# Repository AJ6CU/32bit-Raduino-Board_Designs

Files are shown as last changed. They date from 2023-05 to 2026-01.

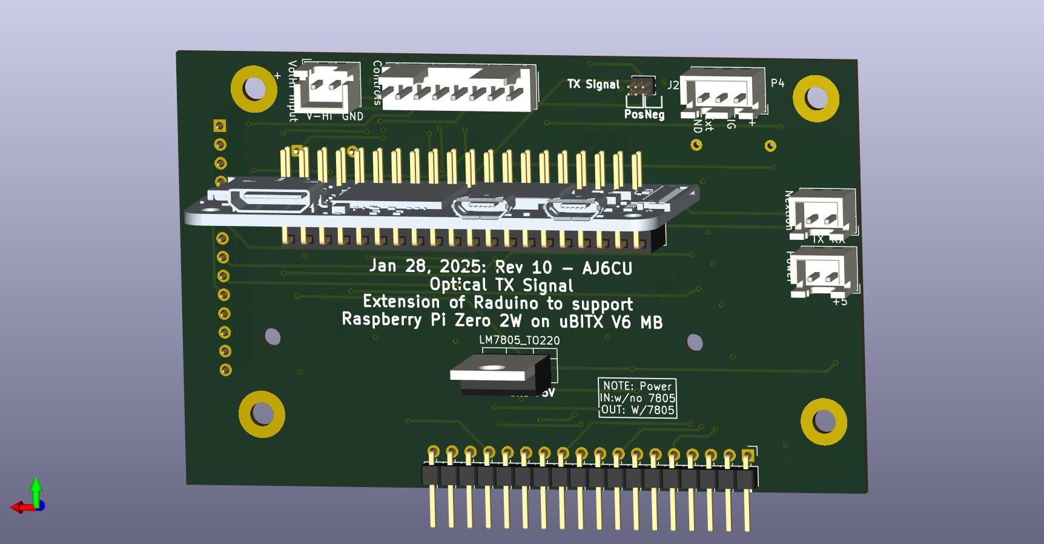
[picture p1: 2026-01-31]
RaduinoClone/RaspberryPiZeroW2/uBitxV6Specific/Images/uBitx V6 Raduino Clone Rev 10-Optic piZero2w-BackView.jpg

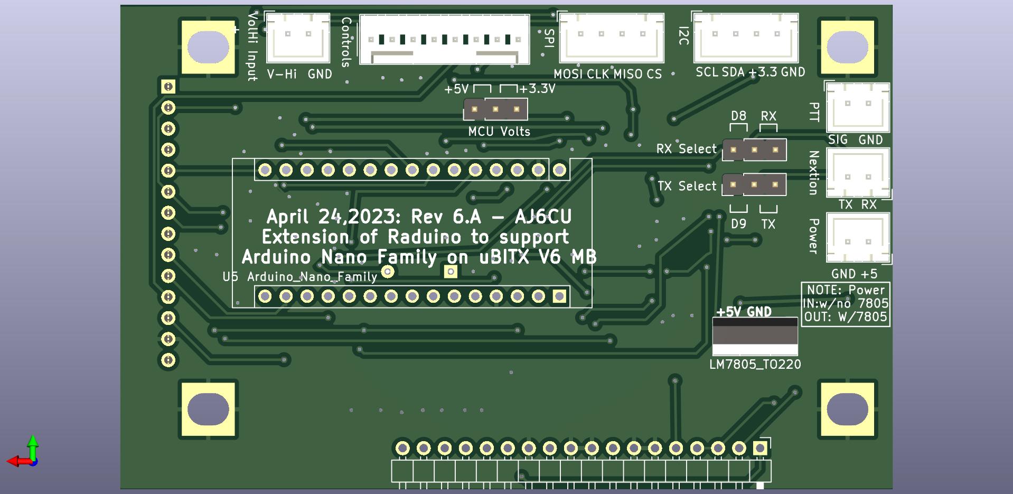
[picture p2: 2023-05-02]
RaduinoClone/Nano Family Nano-Every-IOT-BLE-RP2040/uBitxV6Specific/Images/uBitx V6 Raduino Clone Rev 6.A Arduino Nano Family-rear.jpg

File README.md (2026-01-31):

# An uBitx Raduino for Next Generation Nano, Teensy, RPI PICO and RPI Zero 2W

theheard

The current release of the Raduino board sold by HF Signals only supports the "classic" Arduino nano. This device only has 32kb (actually 30kb with bootloader) of flash, 2kb of sram, and runs at 16mhz. The Classic Nano does have 1kb of EEPROM and is 5V signal compatible which prevents a "drop in replacement" by the new generation of Nano compatible footprint processors. 

The constraint of the "classic" Nano has limited the amount of features that can be implement in firmware. In fact, the popular firmware by Ian Lee (KD8CEC) barely squeezes into the flash memory of the Nano and any new features require tradeoffs of what features are going to be eliminated. It also caused KD8CEC to make some architectural decisions where the UX is implemented on the Nextion screen using some features (i.e. timers) that are difficult to extend and debug. Although I have not looked at the V6 touchscreen software provided by HF Signals, I can reasonably believe that they face a similar contraint as well anybody that wants to hack the software.

The purpose of these boards, are to remove this contraint. Currently the following chips are supported:
  1. Nano
  2. Nano Every
  3. Arduino BLE
  4. Arduino IOT
  5. Arduino RP2040
  6. Teensy 4.0
  7. Raspberry Pi Pico
  8. Raspberry Pi Zero 2W

These boards support both V5 (except for RPI Pico and Zero) and V6. V6 boards require a larger header and the installation of a resister.

73
Mark
AJ6CU

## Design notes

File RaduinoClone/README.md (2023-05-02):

# Raduino Clones
Rev 6.A - May 2, 2023

This directory contains a subdirectory for each processor architecture:

- Nano Family Nano-Every-IOT-BLE-RP2040
- RaspberryPi Pico  
- Teensy 4.0 
- Teensy 4.1

Within each processor directory, there are two subdirectories:

- uBitx V6Specific - this design matches the mechanical and electrial design of the V6 board. The traditional 2x16 LCD header, like in the V6 OEM design, is not on this board. Rather, it includes the TFT LCD design and electrical connections of the V6 TFT LCD.

- uBITX V3456 - this design is compatible with the original Raduino physical characterisics with an LCD header compatible with 2x16. V6 can be supported by using a larger pin header on the bottom and adding the pullup resister. However, this design is likely to have mechanical compatibility problems and so is not recommended for V6 systems using the original V6 case.

And finally each of these directories include:

- BOM - basic bill of materials
- Gerbers - this directory includes a zip file that you should be able to upload to
            your favorite Fab house.
- Images - conceptual 3D models of the board.
- PCBDesign - The designs are done with KiCad V7. You should be able to unzip this backup and directly use it with your tool.
- Schematic - pdf version of the design.

These designs have been sent to the the PCB manufacturer and as of May 2nd, not been tested. There is absolutely no warranty here. Use this at your own risk!

73
Mark Hatch
AJ6CU

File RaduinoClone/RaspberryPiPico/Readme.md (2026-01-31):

Latest version (but untested as of January 31, 2026) is V10. It includes an Optical isolation of TX/RX signal and conversion to a full 3.3V design. Prior version, the Display header was not compatible with the standard V6 2.8 TFT S{I screen. This version should fix this. There is no V10 345 Raduino version.
uBitx V6 Raduino Clone Rev 10-Optic pico-BackView
uBitx V6 Raduino Clone Rev 10-Optic pico-FrontView

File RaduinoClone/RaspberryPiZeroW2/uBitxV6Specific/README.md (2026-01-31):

This is the initial (untested as of January 31, 2026) Raduino V6 using the RPI Zero 2W. There is no software that yet works for this design. My intention is to convert the CEC 2.0 software (see elsewhere in the repositiory) to work with this hardware design.

uBitx V6 Raduino Clone Rev 10-Optic piZero2w-BackView
uBitx V6 Raduino Clone Rev 10-Optic piZero2w-FrontView

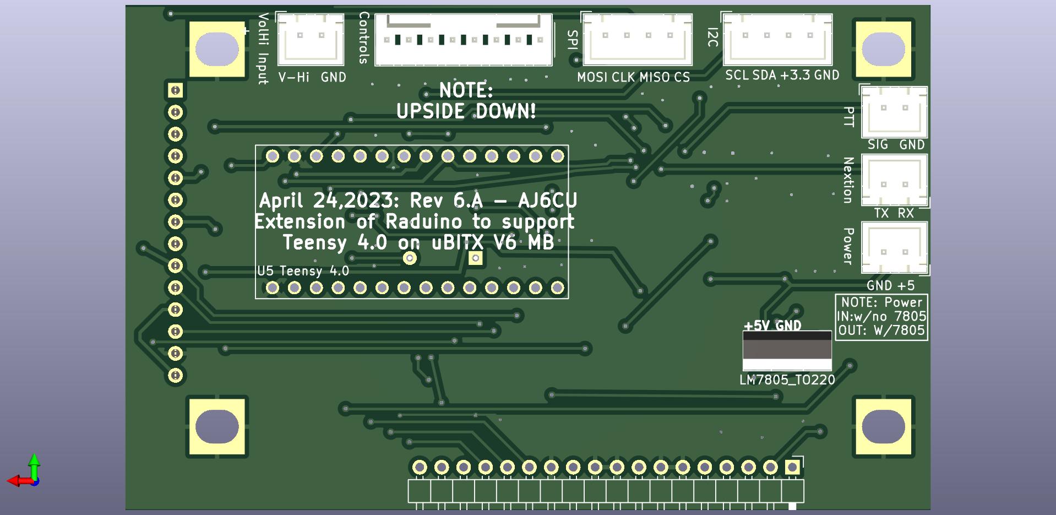
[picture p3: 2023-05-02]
RaduinoClone/Teensy 4.0/uBitxV6Specific/Images/uBitx V6 Raduino Clone Rev 6.A teensy 4.0-rear.jpg

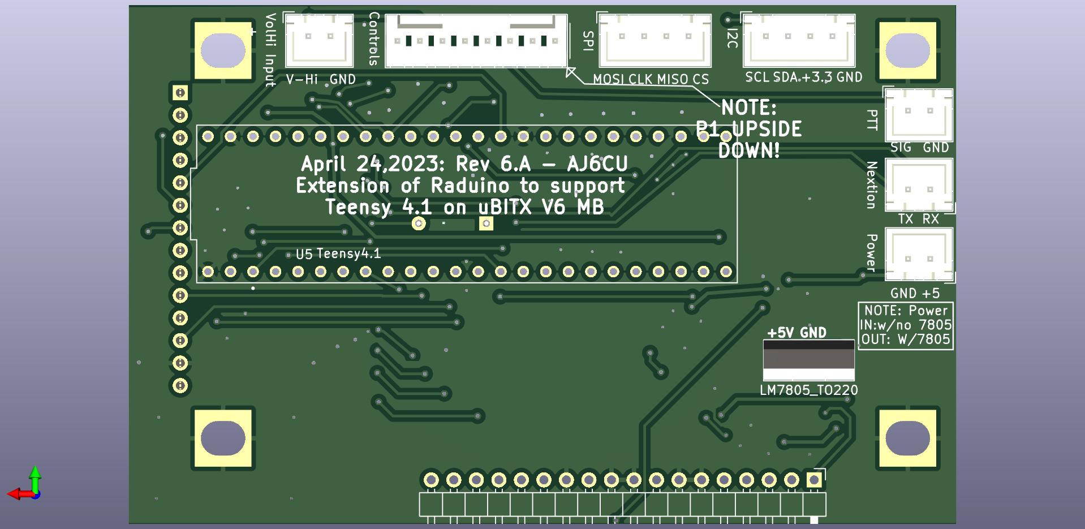
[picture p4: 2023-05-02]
RaduinoClone/Teensy 4.1/uBitxV6Specific/Images/uBitx V6 Raduino Clone Rev 6.A teensy 4.1-rear.jpg

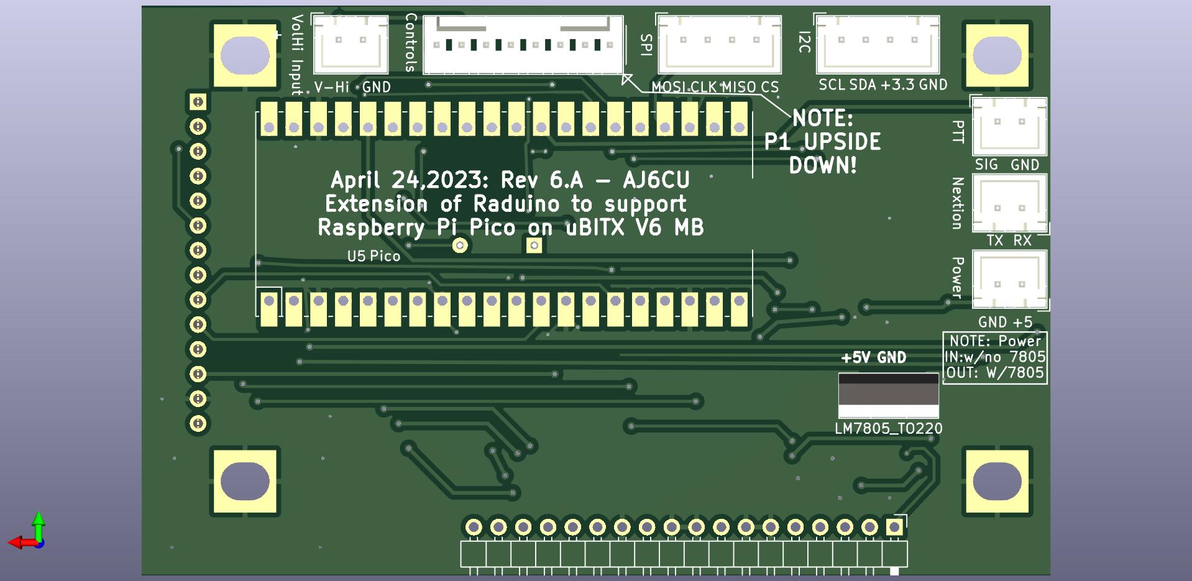
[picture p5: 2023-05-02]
RaduinoClone/RaspberryPiPico/uBitxV6Specific/Images/uBitx V6 Raduino Clone Rev 6.A pico-rear.jpg

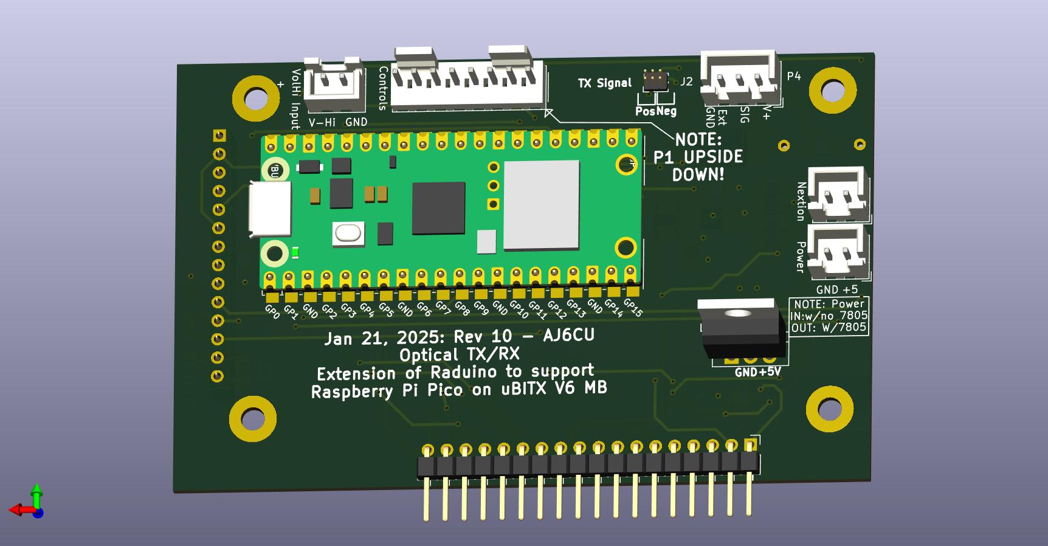
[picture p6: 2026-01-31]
RaduinoClone/RaspberryPiPico/uBitxV6Specific/Images/uBitx V6 Raduino Clone Rev 10-Optic pico-BackView.jpg

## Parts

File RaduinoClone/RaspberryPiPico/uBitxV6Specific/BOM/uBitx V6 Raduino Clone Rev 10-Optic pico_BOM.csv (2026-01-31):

Reference | Qty | Value | DNP | Exclude from BOM | Exclude from Board | Footprint | Datasheet
C1,C2,C4,C5,C6,C8,C11 | 7 | 0.1u |  |  |  | Capacitor_SMD:C_1206_3216Metric | ~
C3 | 1 | 0.3nF |  |  |  | Capacitor_SMD:C_1206_3216Metric | ~
C7 | 1 | 0.33u |  |  |  | Capacitor_SMD:C_1206_3216Metric | ~
C9 | 1 | 1uf |  |  |  | Capacitor_SMD:C_1206_3216Metric | ~
C10 | 1 | 10uf |  |  |  | Capacitor_SMD:C_1206_3216Metric | ~
D1 | 1 | 1N4148 |  |  |  | MyLibrary:tht_SMD_Diode | https://assets.nexperia.com/documents/data-sheet/1N4148_1N4448.pdf
J1 | 1 | LCD DISPLAY |  |  |  | Connector_PinSocket_2.54mm:PinSocket_1x14_P2.54mm_Vertical | ~
J2 | 1 | TX Polarity Sel |  |  |  | Connector_PinHeader_1.00mm:PinHeader_2x03_P1.00mm_Vertical | ~
P1 | 1 | Controls |  |  |  | MyLibrary:Molex_KK-254_AE-6410-08A_1x08_P2.54mm_Vertical-reversed | ~
P2 | 1 | Power |  |  |  | Connector_JST:JST_XH_B2B-XH-A_1x02_P2.50mm_Vertical | ~
P3 | 1 | Oscillators |  |  |  | MyLibrary:PinHeadere_1x18_P2.54mm_Horizontal | ~
P4 | 1 | TX/RX |  |  |  | Connector_JST:JST_XH_B3B-XH-AM_1x03_P2.50mm_Vertical | ~
P5 | 1 | Nextion |  |  |  | Connector_JST:JST_XH_B2B-XH-A_1x02_P2.50mm_Vertical | ~
P7 | 1 | VolHi Input |  |  |  | Connector_JST:JST_XH_B2B-XH-A_1x02_P2.50mm_Vertical | ~
R1 | 1 | 10k |  |  |  | Resistor_SMD:R_1206_3216Metric | ~
R2 | 1 | 1K |  |  |  | Resistor_SMD:R_1206_3216Metric | ~
R3 | 1 | 4.7k |  |  |  | Resistor_SMD:R_1206_3216Metric | ~
R4 | 1 | 22 |  |  |  | Resistor_SMD:R_1206_3216Metric | ~
R5 | 1 | 1k |  |  |  | Resistor_SMD:R_1206_3216Metric | ~
R6 | 1 | 10k |  |  |  | MyLibrary:resistor-tht-1206smd-combo | ~
R13,R14 | 2 | 2.2k |  |  |  | Resistor_SMD:R_1206_3216Metric | ~
U1 | 1 | LM7805_TO220 |  |  |  | Package_TO_SOT_THT:TO-220-3_Vertical | https://www.onsemi.cn/PowerSolutions/document/MC7800-D.PDF
U2 | 1 | Si5351A-B-GT |  |  |  | Package_SO:MSOP-10_3x3mm_P0.5mm | https://www.silabs.com/documents/public/data-sheets/Si5351-B.pdf
U3 | 1 | LM358DR |  |  |  | Package_SO:SOIC-8_3.9x4.9mm_P1.27mm | http://www.ti.com/lit/ds/symlink/lm2904-n.pdf
U4 | 1 | CAT24C256 |  |  |  | Package_SO:SOIC-8_3.9x4.9mm_P1.27mm | https://www.onsemi.cn/PowerSolutions/document/CAT24C256-D.PDF
U5 | 1 | Pico |  |  |  | MyLibrary:RPi_Pico_TH_SMD_defined
U6 | 1 | LTV-817S |  |  |  | Package_DIP:SMDIP-4_W9.53mm | http://www.us.liteon.com/downloads/LTV-817-827-847.PDF
Y1 | 1 | 25M |  |  |  | Crystal:Crystal_SMD_5032-2Pin_5.0x3.2mm | ~

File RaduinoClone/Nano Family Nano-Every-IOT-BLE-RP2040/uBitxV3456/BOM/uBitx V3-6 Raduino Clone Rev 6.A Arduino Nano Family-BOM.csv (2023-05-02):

Item | Qty | Reference(s) | Value | Footprint | Digikey | Comment
1 | 5 | C1, C2, C4, C5, C6 | 0.1u | Capacitor_SMD:C_1206_3216Metric |  | Purchase a "kit" from Amazon, eBay, AliExpress
2 | 1 | C3 | 0.3nF | Capacitor_SMD:C_1206_3216Metric |  | https://www.amazon.com/gp/product/B06XDHC93D/
3 | 1 | C7 | 0.1uF | Capacitor_SMD:C_1206_3216Metric
4 | 1 | C8 | 0.33uF | Capacitor_SMD:C_1206_3216Metric
5 | 1 | D1 | 1N4148TR | Diode_THT:D_DO-35_SOD27_P7.62mm_Horizontal | 1N4148TR
6 | 1 | JP1 | MCU Volts | Connector_PinHeader_2.54mm:PinHeader_1x03_P2.54mm_Vertical |  | Purchase a "kit" from Amazon, eBay, AliExpress
7 | 1 | JP2 | RX Select | Connector_PinHeader_2.54mm:PinHeader_1x03_P2.54mm_Vertical
8 | 1 | JP3 | TX Select | Connector_PinHeader_2.54mm:PinHeader_1x03_P2.54mm_Vertical
9 | 1 | P1 | Controls | Molex_KK-254_AE-6410-08A_1x08_P2.54mm_Vertical |  | https://www.amazon.com/gp/product/B09P3W4VBQ
10 | 1 | P2 | LCD Display | Connector_PinSocket_2.54mm:PinSocket_1x16_P2.54mm_Vertical |  | Purchase a "kit" from Amazon, eBay, AliExpress
11 | 1 | P3 | SPI | Connector_JST:JST_XH_B4B-XH-A_1x04_P2.50mm_Vertical |  | Purchase a "kit" from Amazon, eBay, AliExpress
12 | 1 | P5 | Nextion | Connector_JST:JST_XH_B2B-XH-A_1x02_P2.50mm_Vertical |  | Vertical | https://www.amazon.com/gp/product/B0791DJMW10
13 | 1 | P6 | I2C | Connector_JST:JST_XH_B4B-XH-A_1x04_P2.50mm_Vertical |  | Horizontal | https://www.ebay.com/itm/292219710596
14 | 1 | P7 | VolHi Input | Connector_JST:JST_XH_B2B-XH-A_1x02_P2.50mm_Vertical
15 | 1 | P8 | Oscillators | PinHeader_1x18_P2.54mm_Horizontal
16 | 1 | P9 | PTT | Connector_JST:JST_XH_B2B-XH-A_1x02_P2.50mm_Vertical
17 | 1 | R1 | 10k | Resistor_SMD:R_1206_3216Metric |  | Purchase a "kit" from Amazon, eBay, AliExpress
18 | 1 | R2 | 1K | Resistor_SMD:R_1206_3216Metric |  | https://www.amazon.com/gp/product/B07G4YJCNC
19 | 1 | R3 | 4.7k | Resistor_SMD:R_1206_3216Metric
20 | 2 | R13, R14 | 2.2k | Resistor_SMD:R_1206_3216Metric
21 | 1 | RV1 | 10k | Potentiometer_THT:Potentiometer_Vishay_T73YP_Vertical |  | https://www.amazon.com/gp/product/B082ZVSR8K/
22 | 1 | U1 | Arduino_Nano_v3.x | Arduino_Nano Family (Nano,Every,IOT,BLE, RP2040) upside-down soldered - usb on bottom
23 | 1 | U2 | Si5351A-B-GT | Package_SO:MSOP-10_3x3mm_P0.5mm | 336-2399-5-ND
24 | 1 | U3 | LM358DR | Package_SO:SOIC-8_3.9x4.9mm_P1.27mm | LM358DR2G
25 | 1 | U4 | CAT24C256 | Package_SO:SOIC-8_3.9x4.9mm_P1.27mm | CAT24C256WI-GT3
26 | 1 | U5 | LM7805_TO220 | Package_TO_SOT_THT:TO-220-3_Vertical |  | https://www.amazon.com/gp/product/B01MSE2R8C
27 | 1 | Y1 | 25M | Crystal:Crystal_SMD_5032-2Pin_5.0x3.2mm | 644-1041-2-ND

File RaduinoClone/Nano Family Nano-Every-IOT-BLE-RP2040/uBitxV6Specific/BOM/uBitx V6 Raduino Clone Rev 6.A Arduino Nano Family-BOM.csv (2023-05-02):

Item | Qty | Reference(s) | Value | Description | Digikey | Comment
1 | 6 | C1, C2, C4, C5, C6, C11 | 0.1u | Capacitor_SMD:C_1206_3216Metric |  | Purchase a "kit" from Amazon, eBay, AliExpress
2 | 1 | C3 | 0.3nF | Capacitor_SMD:C_1206_3216Metric |  | https://www.amazon.com/gp/product/B06XDHC93D/
3 | 1 | C7 | 0.33uF | Capacitor_SMD:C_1206_3216Metric
4 | 1 | C8 | 0.1uF | Capacitor_SMD:C_1206_3216Metric
5 | 1 | C9 | 1uf | Capacitor_SMD:C_1206_3216Metric
6 | 1 | C10 | 10uf | Capacitor_SMD:C_1206_3216Metric
7 | 1 | D1 | 1N4148TR | Diode_THT:D_DO-35_SOD27_P7.62mm_Horizontal | 1N4148TR
8 | 1 | J1 | LCD DISPLAY | Connector_PinSocket_2.54mm:PinSocket_1x14_P2.54mm_Vertical |  | Purchase a "kit" from Amazon, eBay, AliExpress
9 | 1 | JP1 | MCU Volts | Connector_PinHeader_2.54mm:PinHeader_1x03_P2.54mm_Vertical |  | Purchase a "kit" from Amazon, eBay, AliExpress
10 | 1 | JP2 | RX Select | Connector_PinHeader_2.54mm:PinHeader_1x03_P2.54mm_Vertical
11 | 1 | JP3 | TX Select | Connector_PinHeader_2.54mm:PinHeader_1x03_P2.54mm_Vertical
12 | 1 | P1 | Controls | Molex_KK-254_AE-6410-08A_1x08_P2.54mm_Vertical-reversed |  | https://www.amazon.com/gp/product/B09P3W4VBQ
13 | 1 | P2 | Power | Connector_JST:JST_XH_B2B-XH-A_1x02_P2.50mm_Vertical
14 | 1 | P3 | Oscillators | PinHeader_x18_P2.54mm_Horizontal
15 | 1 | P5 | Nextion | Connector_JST:JST_XH_B2B-XH-A_1x02_P2.50mm_Vertical |  | Purchase a "kit" from Amazon, eBay, AliExpress
16 | 1 | P6 | I2C | Connector_JST:JST_XH_B4B-XH-A_1x04_P2.50mm_Vertical |  | Vertical | https://www.amazon.com/gp/product/B0791DJMW10
17 | 1 | P7 | VolHi Input | Connector_JST:JST_XH_B2B-XH-A_1x02_P2.50mm_Vertical |  | Horizontal | https://www.ebay.com/itm/292219710596
18 | 1 | P8 | SPI | Connector_JST:JST_XH_B4B-XH-A_1x04_P2.50mm_Vertical
19 | 1 | P9 | PTT | Connector_JST:JST_XH_B2B-XH-A_1x02_P2.50mm_Vertical
20 | 1 | R1 | 10k | Resistor_SMD:R_1206_3216Metric |  | Purchase a "kit" from Amazon, eBay, AliExpress
21 | 1 | R2 | 1K | Resistor_SMD:R_1206_3216Metric |  | https://www.amazon.com/gp/product/B07G4YJCNC
22 | 1 | R3 | 4.7k | Resistor_SMD:R_1206_3216Metric
23 | 1 | R4 | 22R | Resistor_SMD:R_1206_3216Metric
24 | 2 | R13, R14 | 2.2k | Resistor_SMD:R_1206_3216Metric
25 | 1 | U1 | LM7805_TO220 | Package_TO_SOT_THT:TO-220-3_Vertical |  | https://www.amazon.com/gp/product/B01MSE2R8C
26 | 1 | U2 | Si5351A-B-GT | Package_SO:MSOP-10_3x3mm_P0.5mm | 336-2399-5-ND
27 | 1 | U3 | LM358DR | Package_SO:SOIC-8_3.9x4.9mm_P1.27mm | LM358DR2G
28 | 1 | U4 | CAT24C256 | Package_SO:SOIC-8_3.9x4.9mm_P1.27mm | CAT24C256WI-GT3
29 | 1 | U5 | Arduino_Nano_Family | Nano: Nano V3.0, Every, IOT, BLE, RP2040
30 | 1 | Y1 | 25M | Crystal:Crystal_SMD_5032-2Pin_5.0x3.2mm | 644-1041-2-ND

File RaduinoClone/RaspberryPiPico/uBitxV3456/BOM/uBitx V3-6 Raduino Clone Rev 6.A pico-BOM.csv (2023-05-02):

Item | Qty | Reference(s) | Value | Description | Digikey | Comment
1 | 5 | C1, C2, C4, C5, C6 | 0.1u | Capacitor_SMD:C_1206_3216Metric |  | Purchase a "kit" from Amazon, eBay, AliExpress
2 | 1 | C3 | 0.3nF | Capacitor_SMD:C_1206_3216Metric |  | https://www.amazon.com/gp/product/B06XDHC93D/
3 | 1 | C7 | 0.1uF | Capacitor_SMD:C_1206_3216Metric
4 | 1 | C8 | 0.33uF | Capacitor_SMD:C_1206_3216Metric
5 | 1 | D1 | 1N4148TR | Diode_THT:D_DO-35_SOD27_P7.62mm_Horizontal | 1N4148TR
6 | 1 | P1 | Controls | Molex_KK-254_AE-6410-08A_1x08_P2.54mm_Vertical |  | https://www.amazon.com/gp/product/B09P3W4VBQ
7 | 1 | P2 | LCD Display | Connector_PinSocket_2.54mm:PinSocket_1x16_P2.54mm_Vertical |  | Purchase a "kit" from Amazon, eBay, AliExpress
8 | 1 | P3 | Oscillators | PinHeader_1x18_P2.54mm_Horizontal |  | Purchase a "kit" from Amazon, eBay, AliExpress
9 | 1 | P5 | Nextion | Connector_JST:JST_XH_B2B-XH-A_1x02_P2.50mm_Vertical |  | Purchase a "kit" from Amazon, eBay, AliExpress
10 | 1 | P6 | I2C | Connector_JST:JST_XH_B4B-XH-A_1x04_P2.50mm_Vertical |  | Vertical | https://www.amazon.com/gp/product/B0791DJMW10
11 | 1 | P7 | VolHi Input | Connector_JST:JST_XH_B2B-XH-A_1x02_P2.50mm_Vertical |  | Horizontal | https://www.ebay.com/itm/292219710596
12 | 1 | P8 | SPI | Connector_JST:JST_XH_B4B-XH-A_1x04_P2.50mm_Vertical
13 | 1 | P9 | PTT | Connector_JST:JST_XH_B2B-XH-A_1x02_P2.50mm_Vertical
14 | 1 | R1 | 10k | Resistor_SMD:R_1206_3216Metric |  | Purchase a "kit" from Amazon, eBay, AliExpress
15 | 1 | R2 | 1K | Resistor_SMD:R_1206_3216Metric |  | https://www.amazon.com/gp/product/B07G4YJCNC
16 | 1 | R3 | 4.7k | Resistor_SMD:R_1206_3216Metric
17 | 2 | R13, R14 | 2.2k | Resistor_SMD:R_1206_3216Metric
18 | 1 | RV1 | 10k | Potentiometer_THT:Potentiometer_Vishay_T73YP_Vertical |  | https://www.amazon.com/gp/product/B082ZVSR8K/
19 | 1 | U1 | LM7805_TO220 | Package_TO_SOT_THT:TO-220-3_Vertical |  | https://www.amazon.com/gp/product/B01MSE2R8C
20 | 1 | U2 | Si5351A-B-GT | Package_SO:MSOP-10_3x3mm_P0.5mm | 336-2399-5-ND
21 | 1 | U3 | LM358DR | Package_SO:SOIC-8_3.9x4.9mm_P1.27mm | LM358DR2G
22 | 1 | U4 | CAT24C256 | Package_SO:SOIC-8_3.9x4.9mm_P1.27mm | CAT24C256WI-GT3
23 | 1 | U5 | Pico | Raspberry Pi Pico/Pico-W
24 | 1 | Y1 | 25M | Crystal:Crystal_SMD_5032-2Pin_5.0x3.2mm | 644-1041-2-ND

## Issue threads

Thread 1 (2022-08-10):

RX/TX and D8/D9 do not agree.

AJ6CU, 2022-08-10:
Revise wiring to ensure the RX pins (RX0 and D8, TX0 and D9). Have to flip the connector when switching between RX/TX and D8/D9.

AJ6CU, 2022-10-26:
fixed in v3

Closed 2022-10-26.

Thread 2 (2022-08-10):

s-meter chip footprint too small for human soldering

AJ6CU, 2022-08-10:
The 358 chip surface mount footprint is very small. Probably beyond most people's capability. Need to select a larger footprint.

AJ6CU, 2022-08-15:
wrong footprint on board. real footprint is human solderable.

AJ6CU, 2022-10-26:
fixed in v3

Closed 2022-08-15.

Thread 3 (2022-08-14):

wrong footprint for LM358DR

AJ6CU, 2022-08-14:

AJ6CU, 2022-10-26:
fixed in v3

Closed 2022-10-26.

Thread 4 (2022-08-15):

Voltage Hi input too far away from volume put.

AJ6CU, 2022-08-15:
Connector needs to be moved to right side to minimize length of cable.

AJ6CU, 2022-10-26:
fixed in v3

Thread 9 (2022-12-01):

boards sit too low for V6 and use of LCD

AJ6CU, 2022-12-01:
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

AJ6CU, 2023-04-25:
creating seperate v6 raduino. V3,4,5  all in one not expected to fit. v6

Closed 2023-04-25.

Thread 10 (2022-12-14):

LCD en/rs pins not the same on all boards

AJ6CU, 2022-12-14:
Probably should always be D8 and D( as in original.

AJ6CU, 2023-03-21:
Also Rapsberrypi Pico needs to be changed.

AJ6CU, 2023-04-24:
Fixed on Pico. Breaks accessibility of RX/TX for nextion from the LCD header.

AJ6CU, 2023-04-25:
fixed in v5 on teensy and pico

Closed 2023-04-25.

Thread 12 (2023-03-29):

move the fbutton on pico to gpio28_ADC2 to allow use of extended button feature of KD8CEC

AJ6CU, 2023-03-29:

AJ6CU, 2023-04-24:
fixed in v5

Closed 2023-04-24.

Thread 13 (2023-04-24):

teensy add support for pins on underside of the board

AJ6CU, 2023-04-24:
This is in  prep for use of airlift for web access.

AJ6CU, 2023-04-27:
decided to defer this. Teensy 4.0 SPI pins continue to conflict with LED.

Closed 2023-04-27.

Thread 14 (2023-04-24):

add header for spi bus to  support air lift.

AJ6CU, 2023-04-24:
this function on nanos will be a tradeoff between lcd and extended filter support. can't have everything.

AJ6CU, 2023-04-26:
done on teensy and pico. Needs to be done on Arduino board.

AJ6CU, 2023-04-27:
done

Closed 2023-04-27.

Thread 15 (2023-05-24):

on pico v6 (and probably 3-5, swap encoder B and encoder A pins to be consistent with rest of world.

AJ6CU, 2023-05-24:

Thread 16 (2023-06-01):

spi header should be order of data lines

AJ6CU, 2023-06-01:
Currently, the SPI header is:
Pin     GPIO   Function
1        D11     Mosi
2        D13     SCK
3        D12     MISO
4        D10     SS

The header should be in order of the GPIO pins
1        D10     SS
2        D11     MOSI
3        D12     MISO
4        D13     SCK

This would allow easier use of this header for the extended filters functionality. The 4 pins could be used to identify band and help drive selection of antenna (for example).

No harm the way they are, just weird and no reason they are in that order...

Might want to check other offboard connectors to see if they are similarly messed up.

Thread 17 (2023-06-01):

PTT header not what it was supposed to be...

AJ6CU, 2023-06-01:
The original idea for the PTT header was to drive a RF switch between the radio and an attached SDR. However, the PTT line is an input of the microphone and *not* turned on during CW or other modes.   The T/R pin (D7) was what I was looking for.

Logic is reversed, T is positive and R is negative. Would require an inverter to use for an rf switch.

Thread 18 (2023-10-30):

Pico (and perhaps other) LCD display that supports SPI displays using wrong pins

AJ6CU, 2023-10-30:
Designs up thru V7 of Pico are not using the right pins on the LCD/TFT header. Specifically:

PIN      v7     v8(in draft)
SCK     13     10
CS       10     13
D_C     9       8
Touch  8       9

Pin selection probably was related to mthe original LCD 2x16 header and the pins have changed for SPI bus#1 on the PICO

This is fixed on the schematic for V8 but not yet propagated to board level.

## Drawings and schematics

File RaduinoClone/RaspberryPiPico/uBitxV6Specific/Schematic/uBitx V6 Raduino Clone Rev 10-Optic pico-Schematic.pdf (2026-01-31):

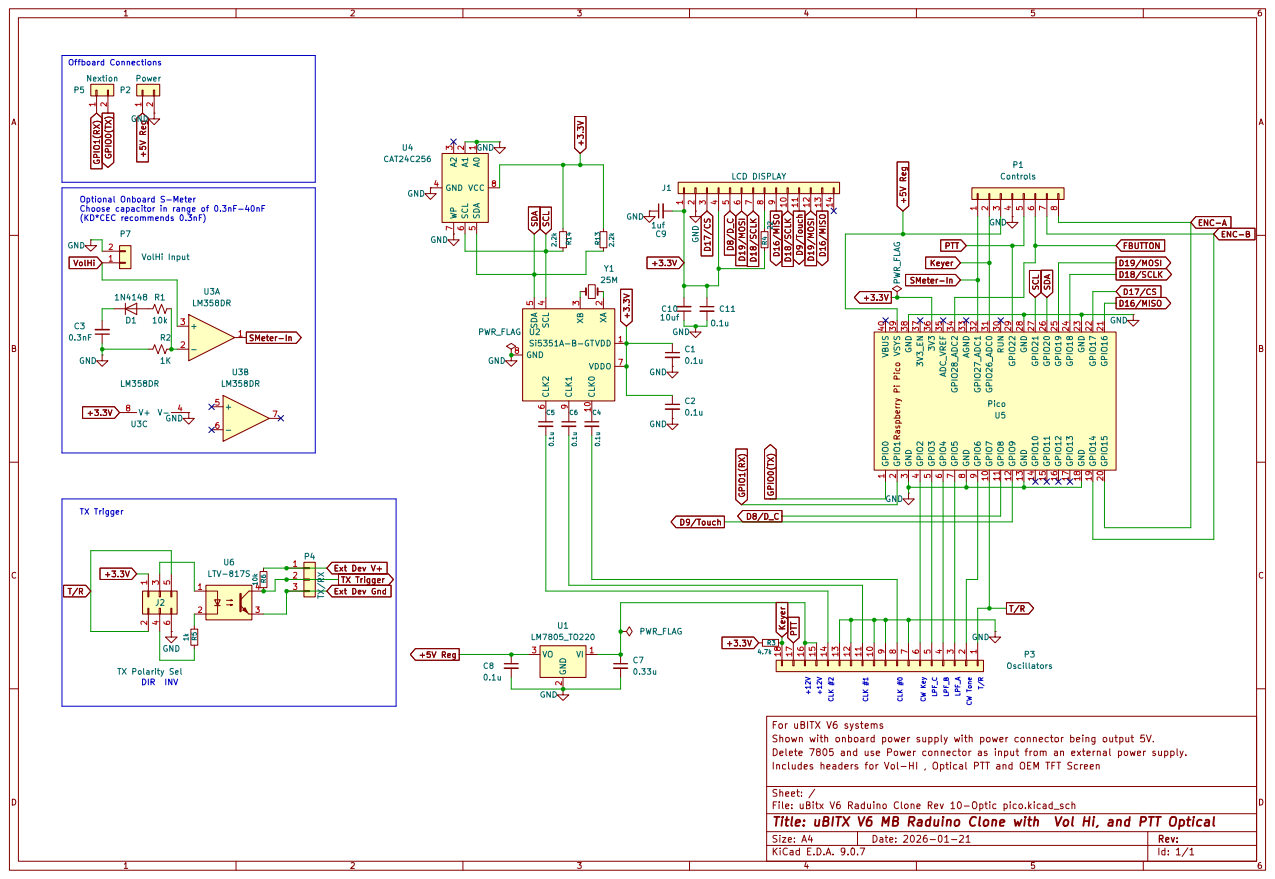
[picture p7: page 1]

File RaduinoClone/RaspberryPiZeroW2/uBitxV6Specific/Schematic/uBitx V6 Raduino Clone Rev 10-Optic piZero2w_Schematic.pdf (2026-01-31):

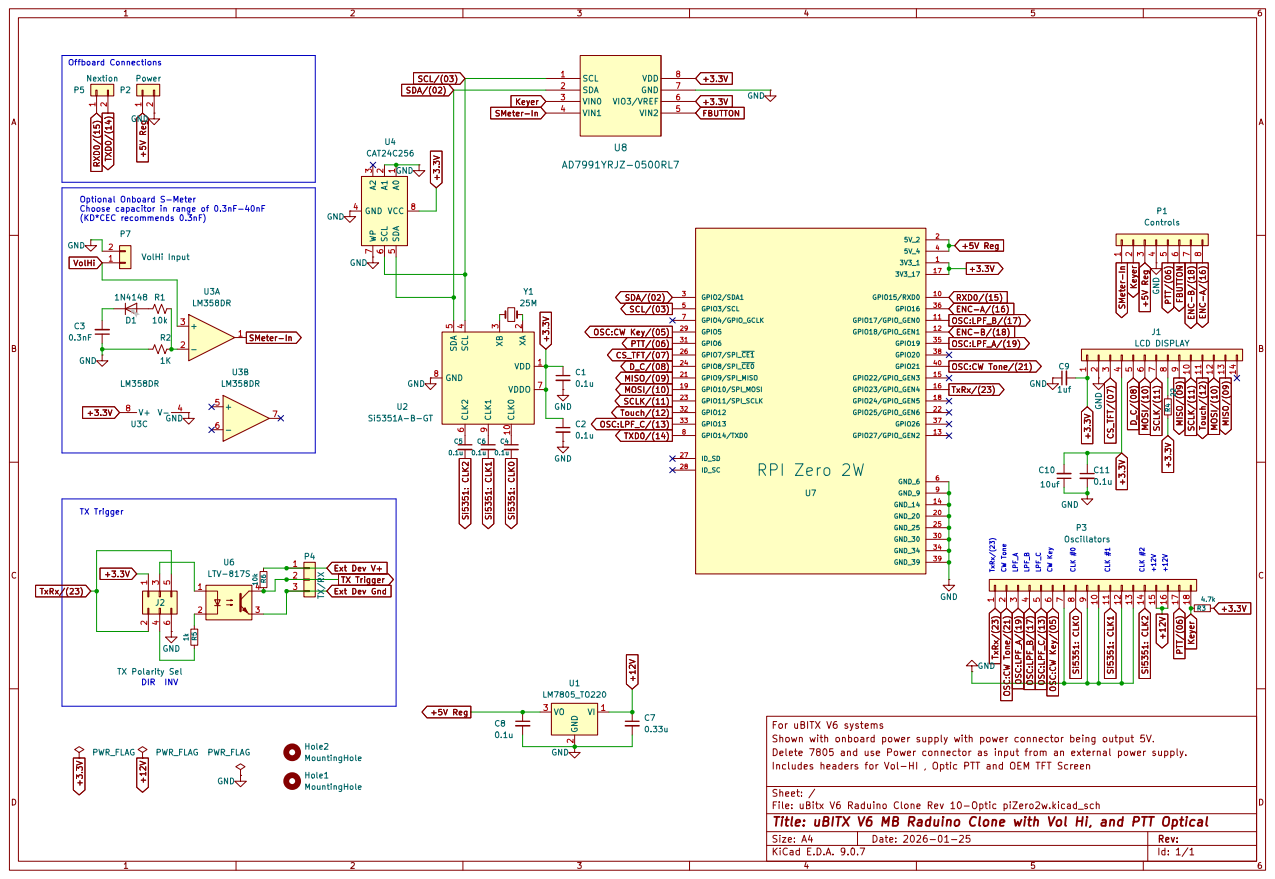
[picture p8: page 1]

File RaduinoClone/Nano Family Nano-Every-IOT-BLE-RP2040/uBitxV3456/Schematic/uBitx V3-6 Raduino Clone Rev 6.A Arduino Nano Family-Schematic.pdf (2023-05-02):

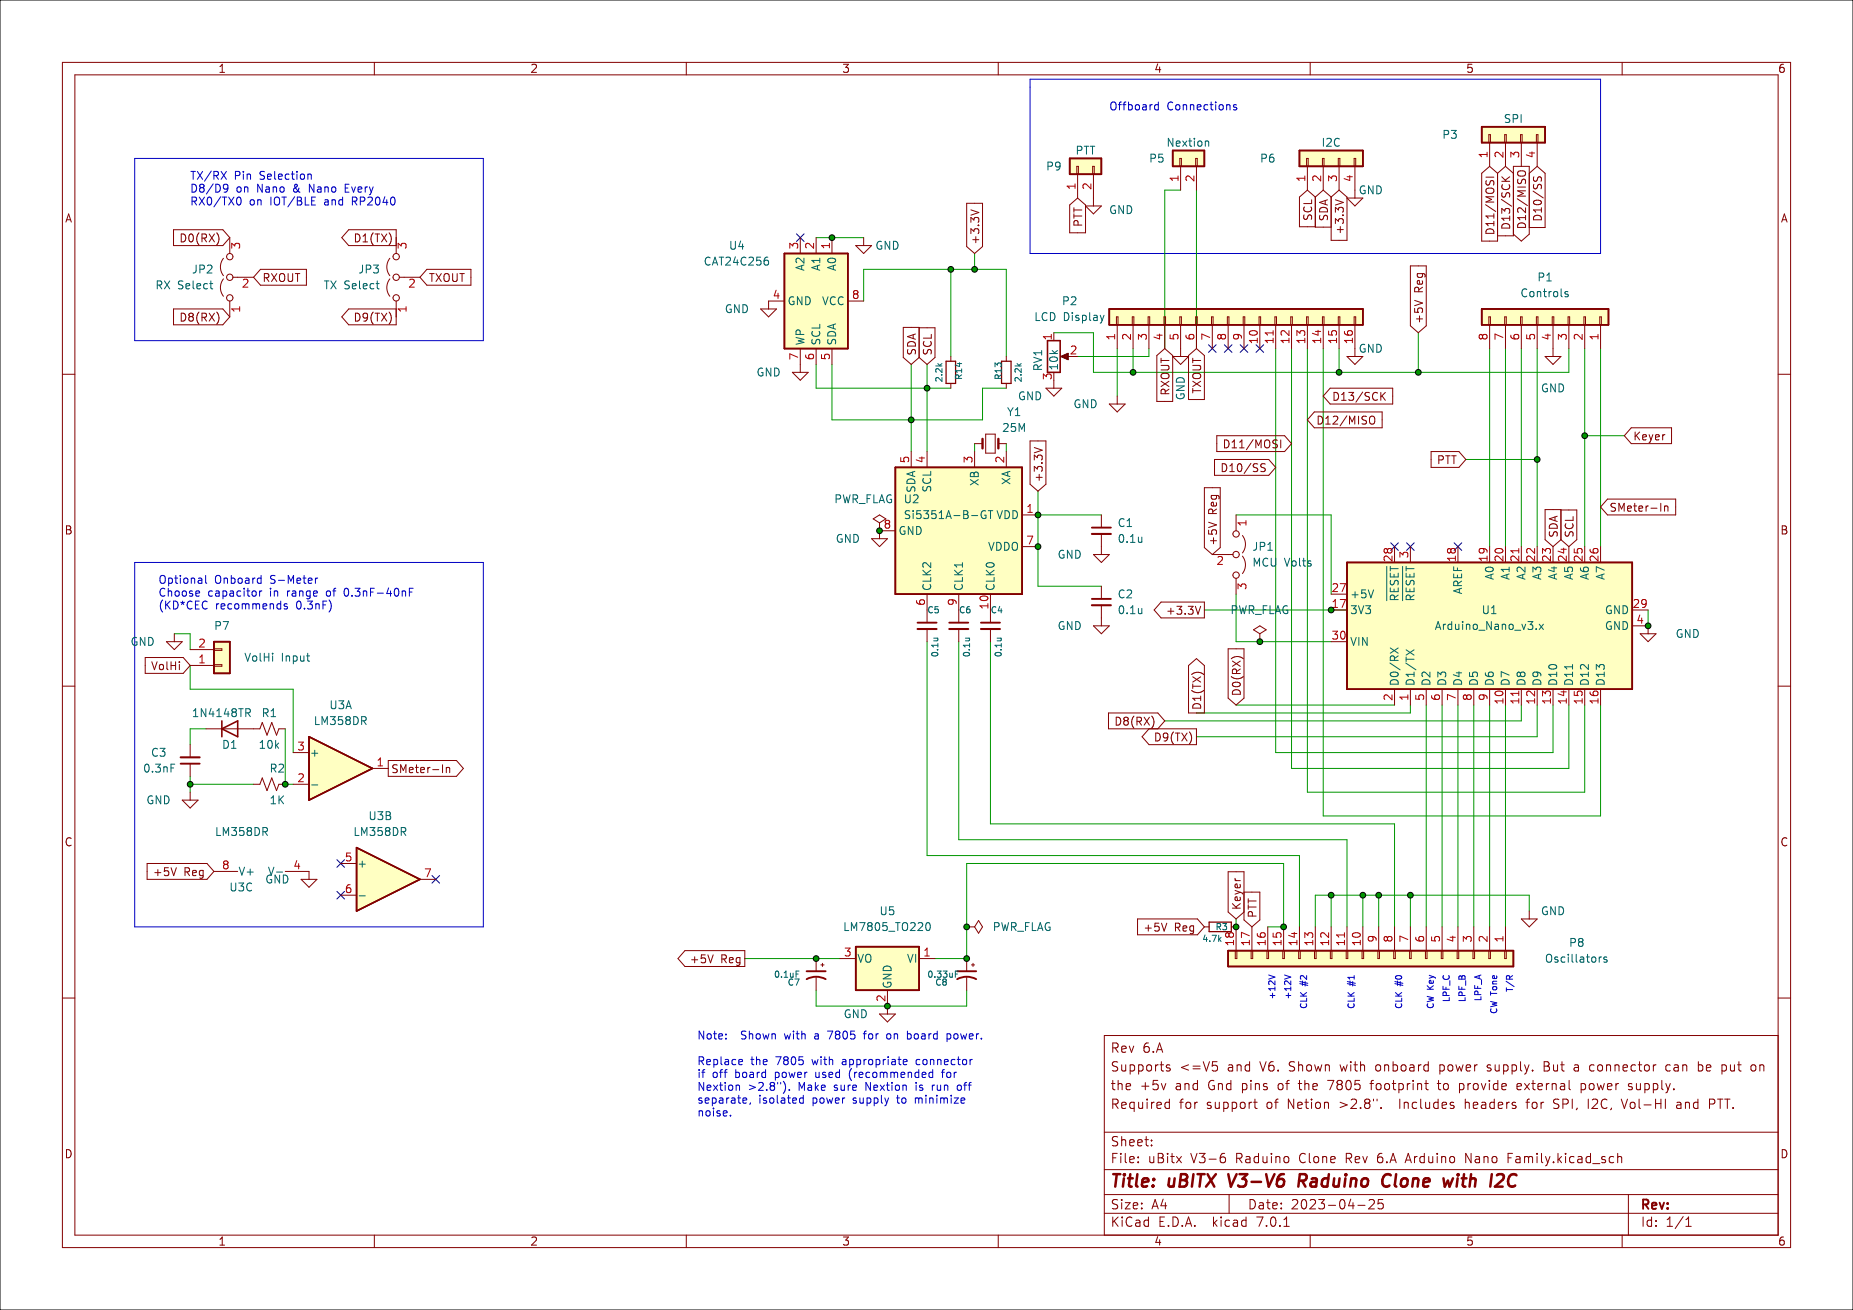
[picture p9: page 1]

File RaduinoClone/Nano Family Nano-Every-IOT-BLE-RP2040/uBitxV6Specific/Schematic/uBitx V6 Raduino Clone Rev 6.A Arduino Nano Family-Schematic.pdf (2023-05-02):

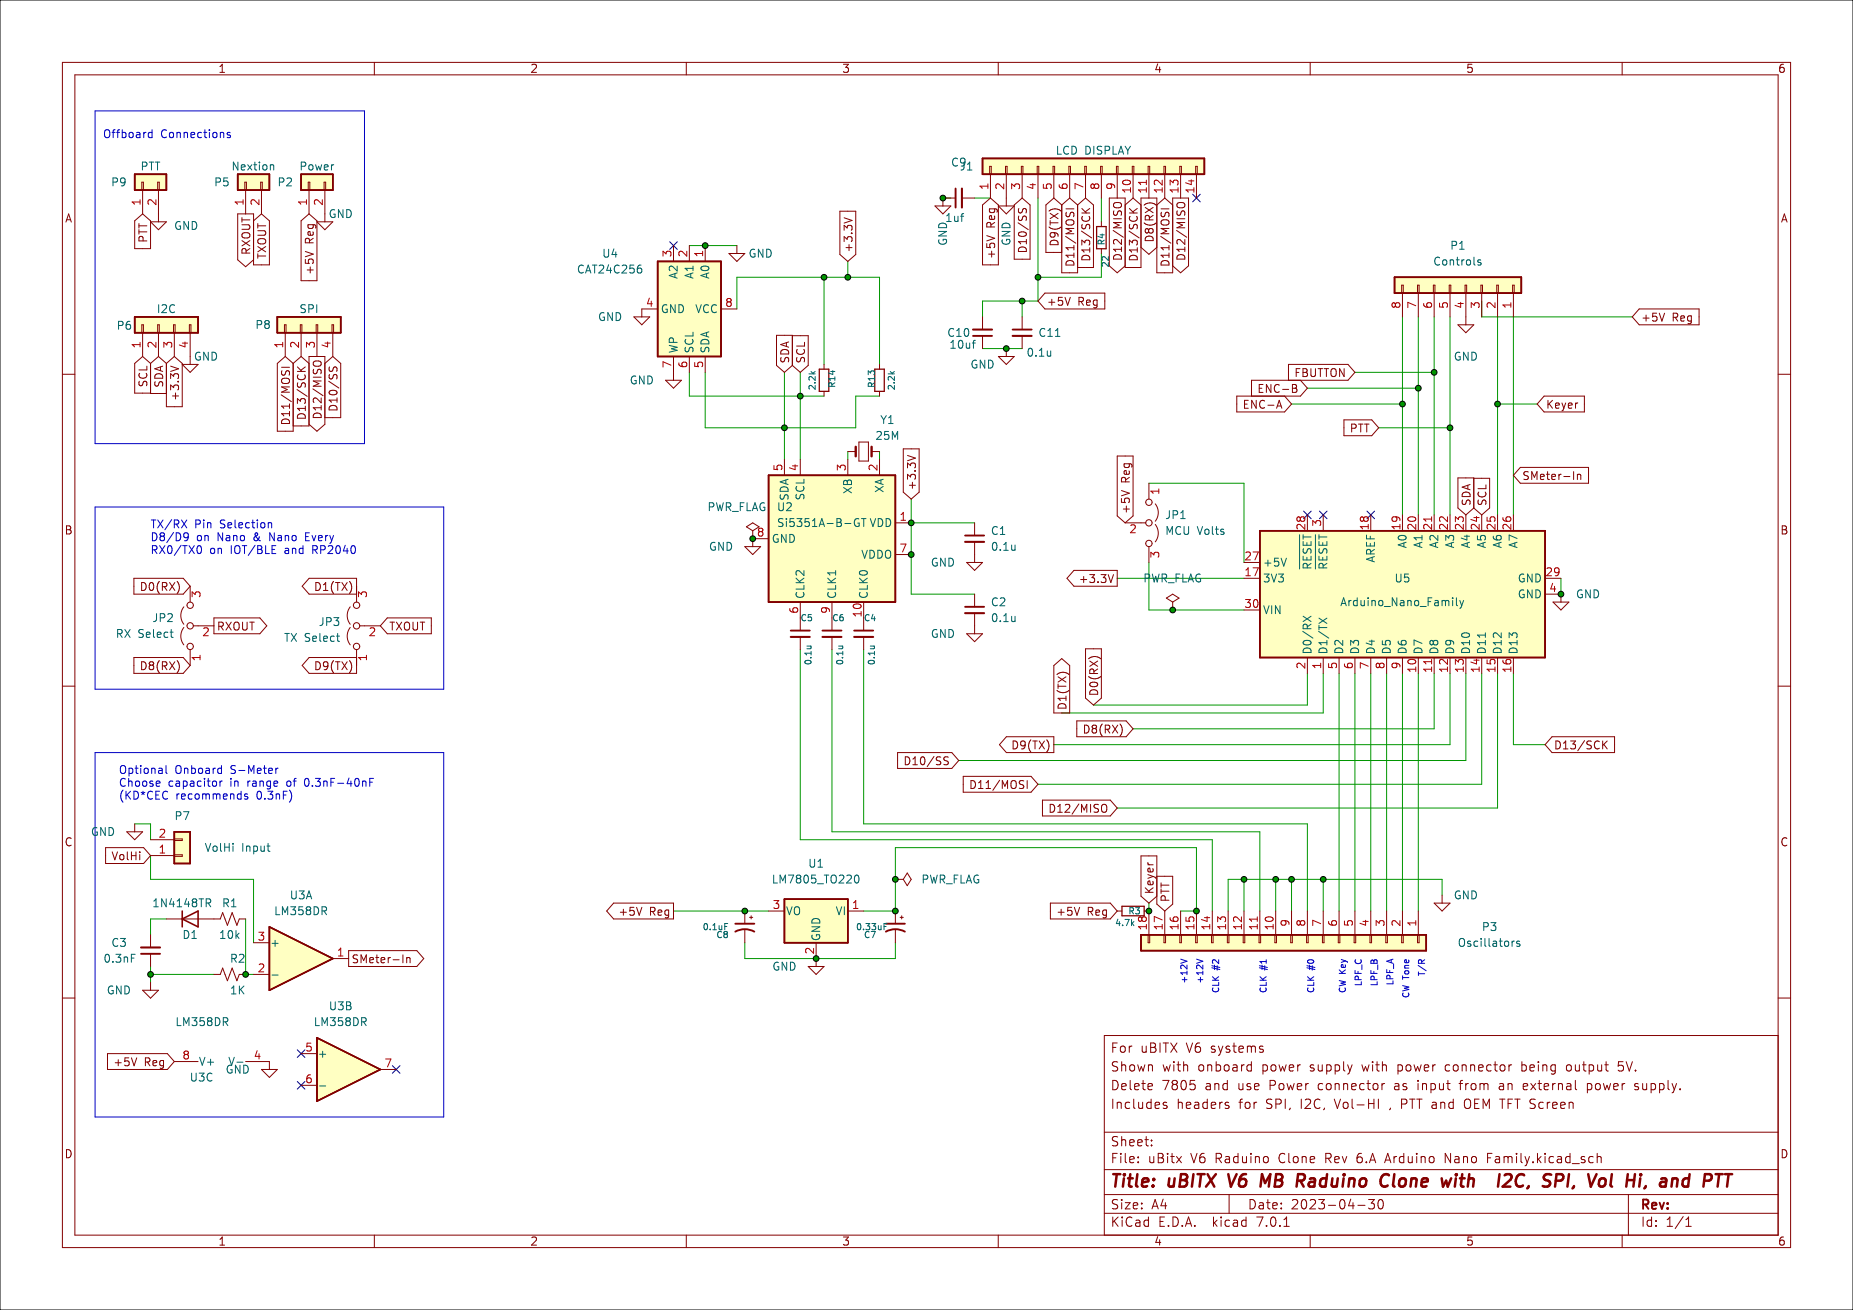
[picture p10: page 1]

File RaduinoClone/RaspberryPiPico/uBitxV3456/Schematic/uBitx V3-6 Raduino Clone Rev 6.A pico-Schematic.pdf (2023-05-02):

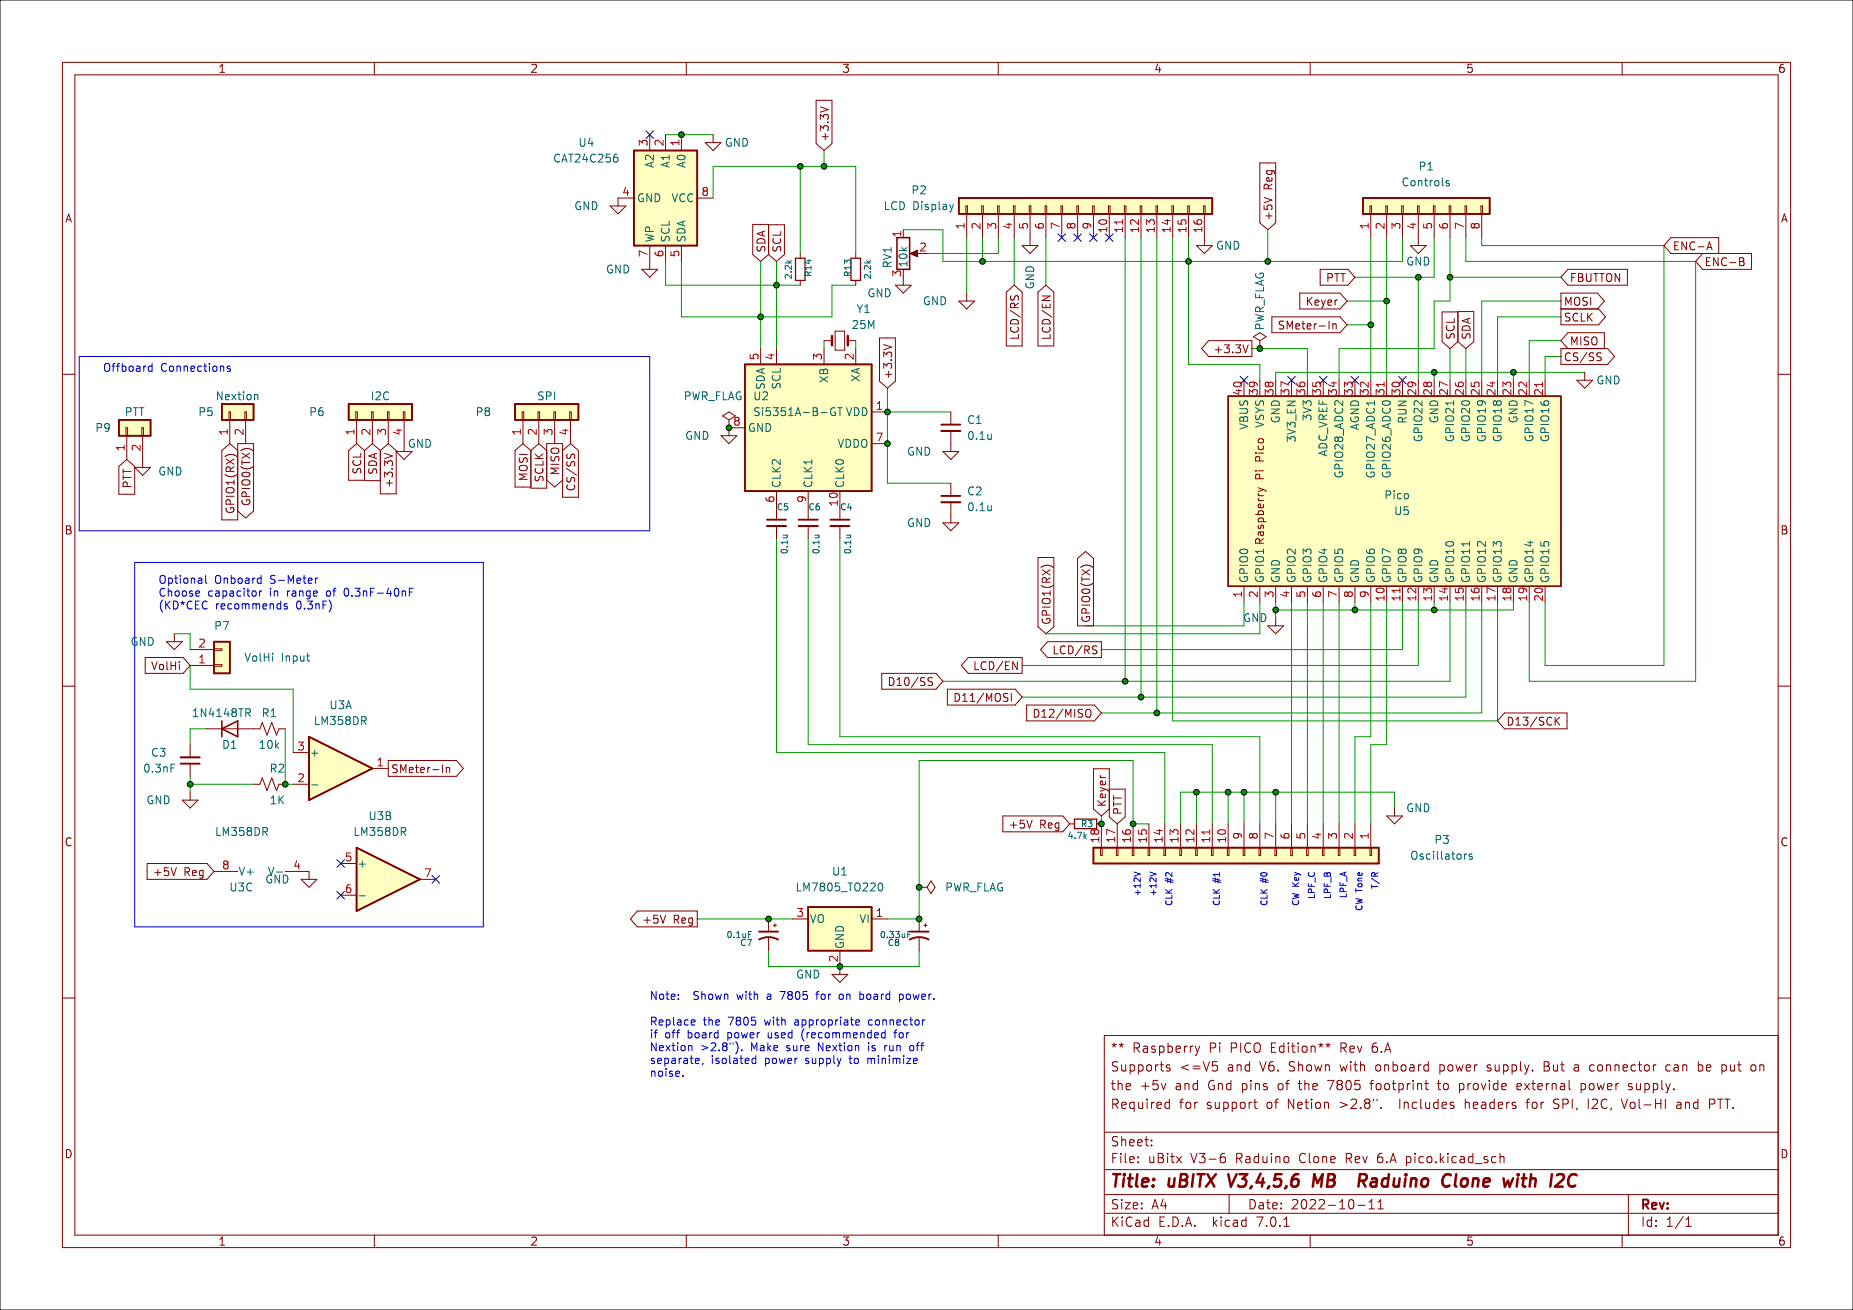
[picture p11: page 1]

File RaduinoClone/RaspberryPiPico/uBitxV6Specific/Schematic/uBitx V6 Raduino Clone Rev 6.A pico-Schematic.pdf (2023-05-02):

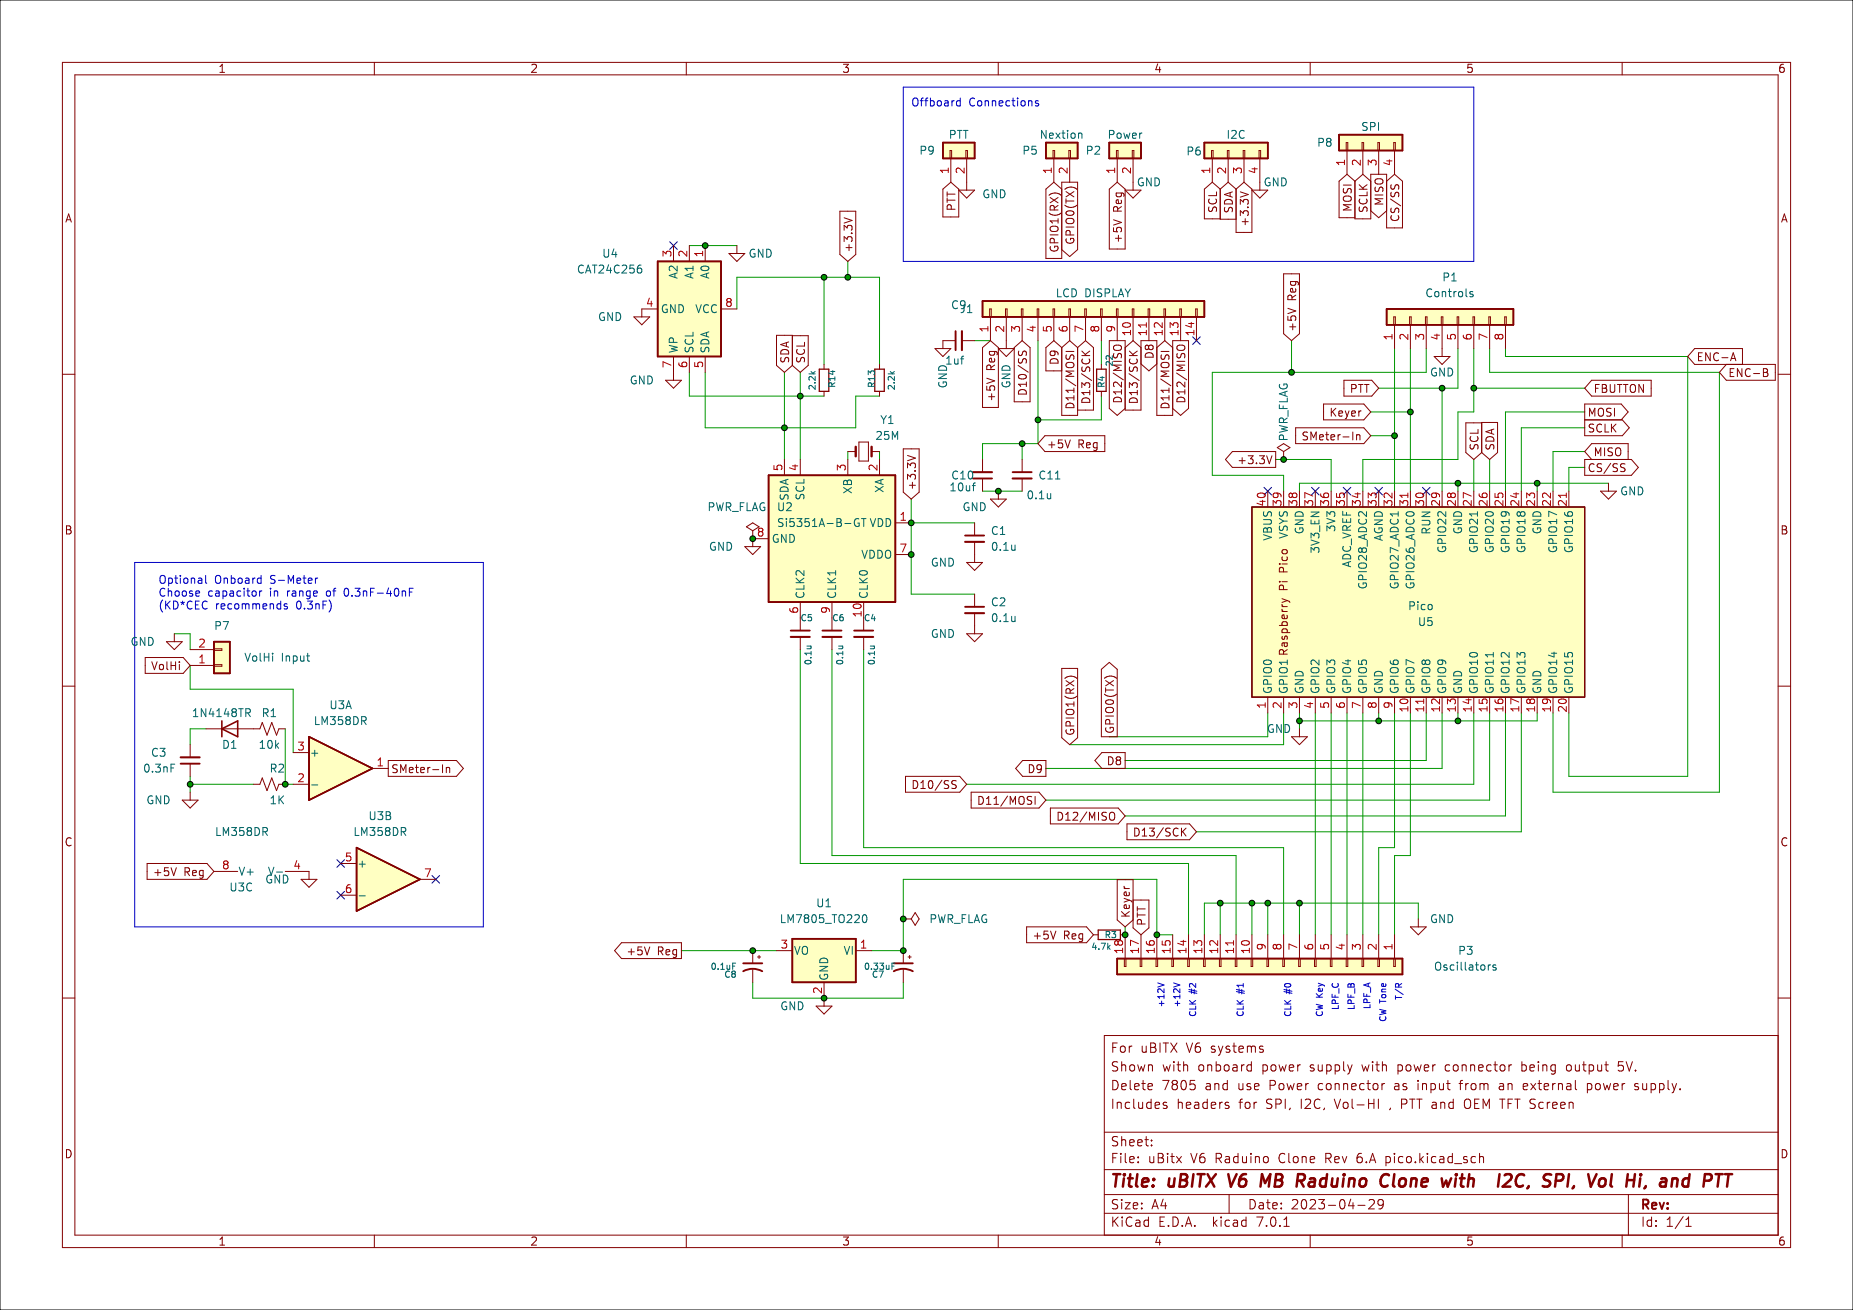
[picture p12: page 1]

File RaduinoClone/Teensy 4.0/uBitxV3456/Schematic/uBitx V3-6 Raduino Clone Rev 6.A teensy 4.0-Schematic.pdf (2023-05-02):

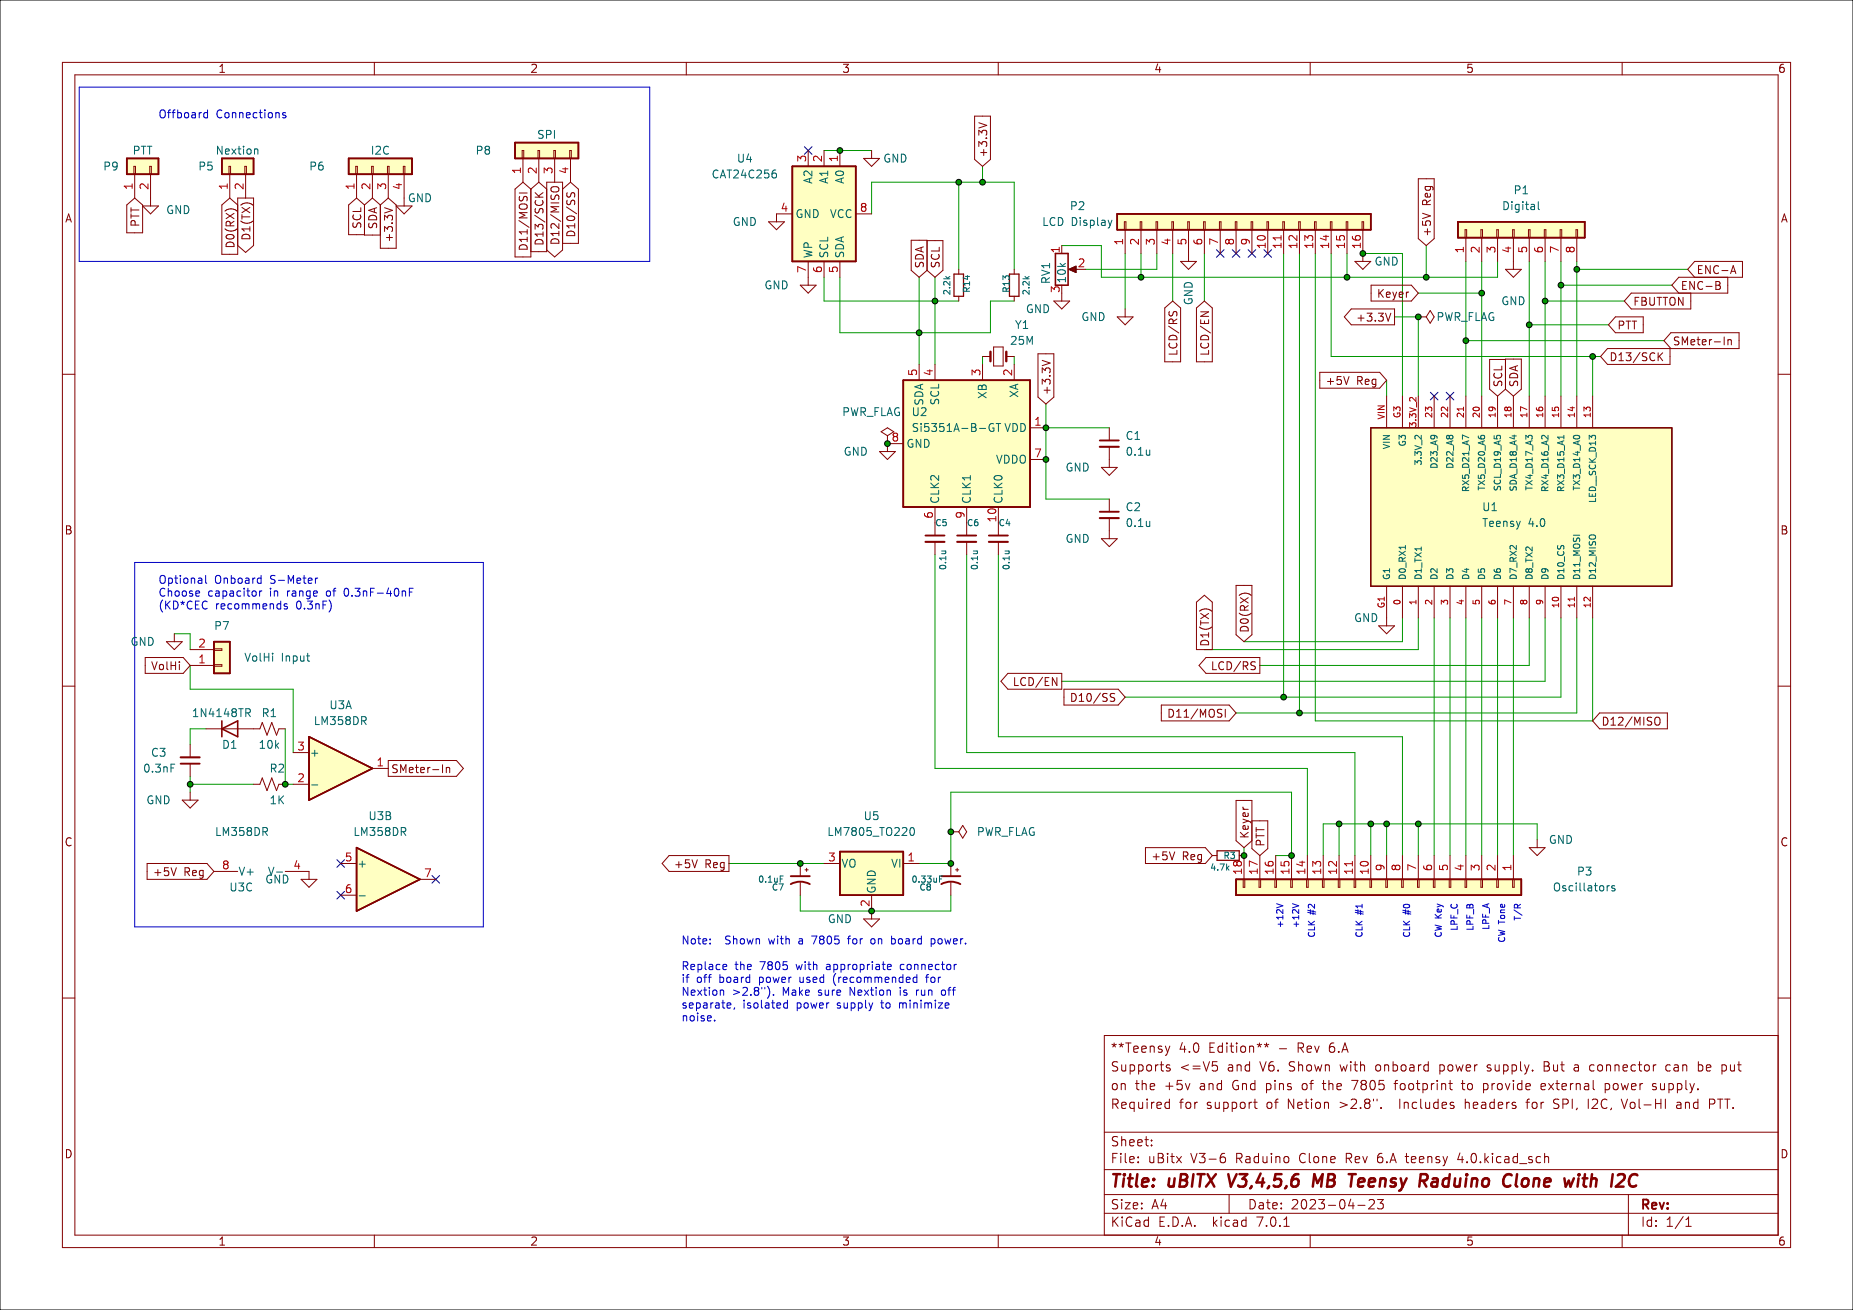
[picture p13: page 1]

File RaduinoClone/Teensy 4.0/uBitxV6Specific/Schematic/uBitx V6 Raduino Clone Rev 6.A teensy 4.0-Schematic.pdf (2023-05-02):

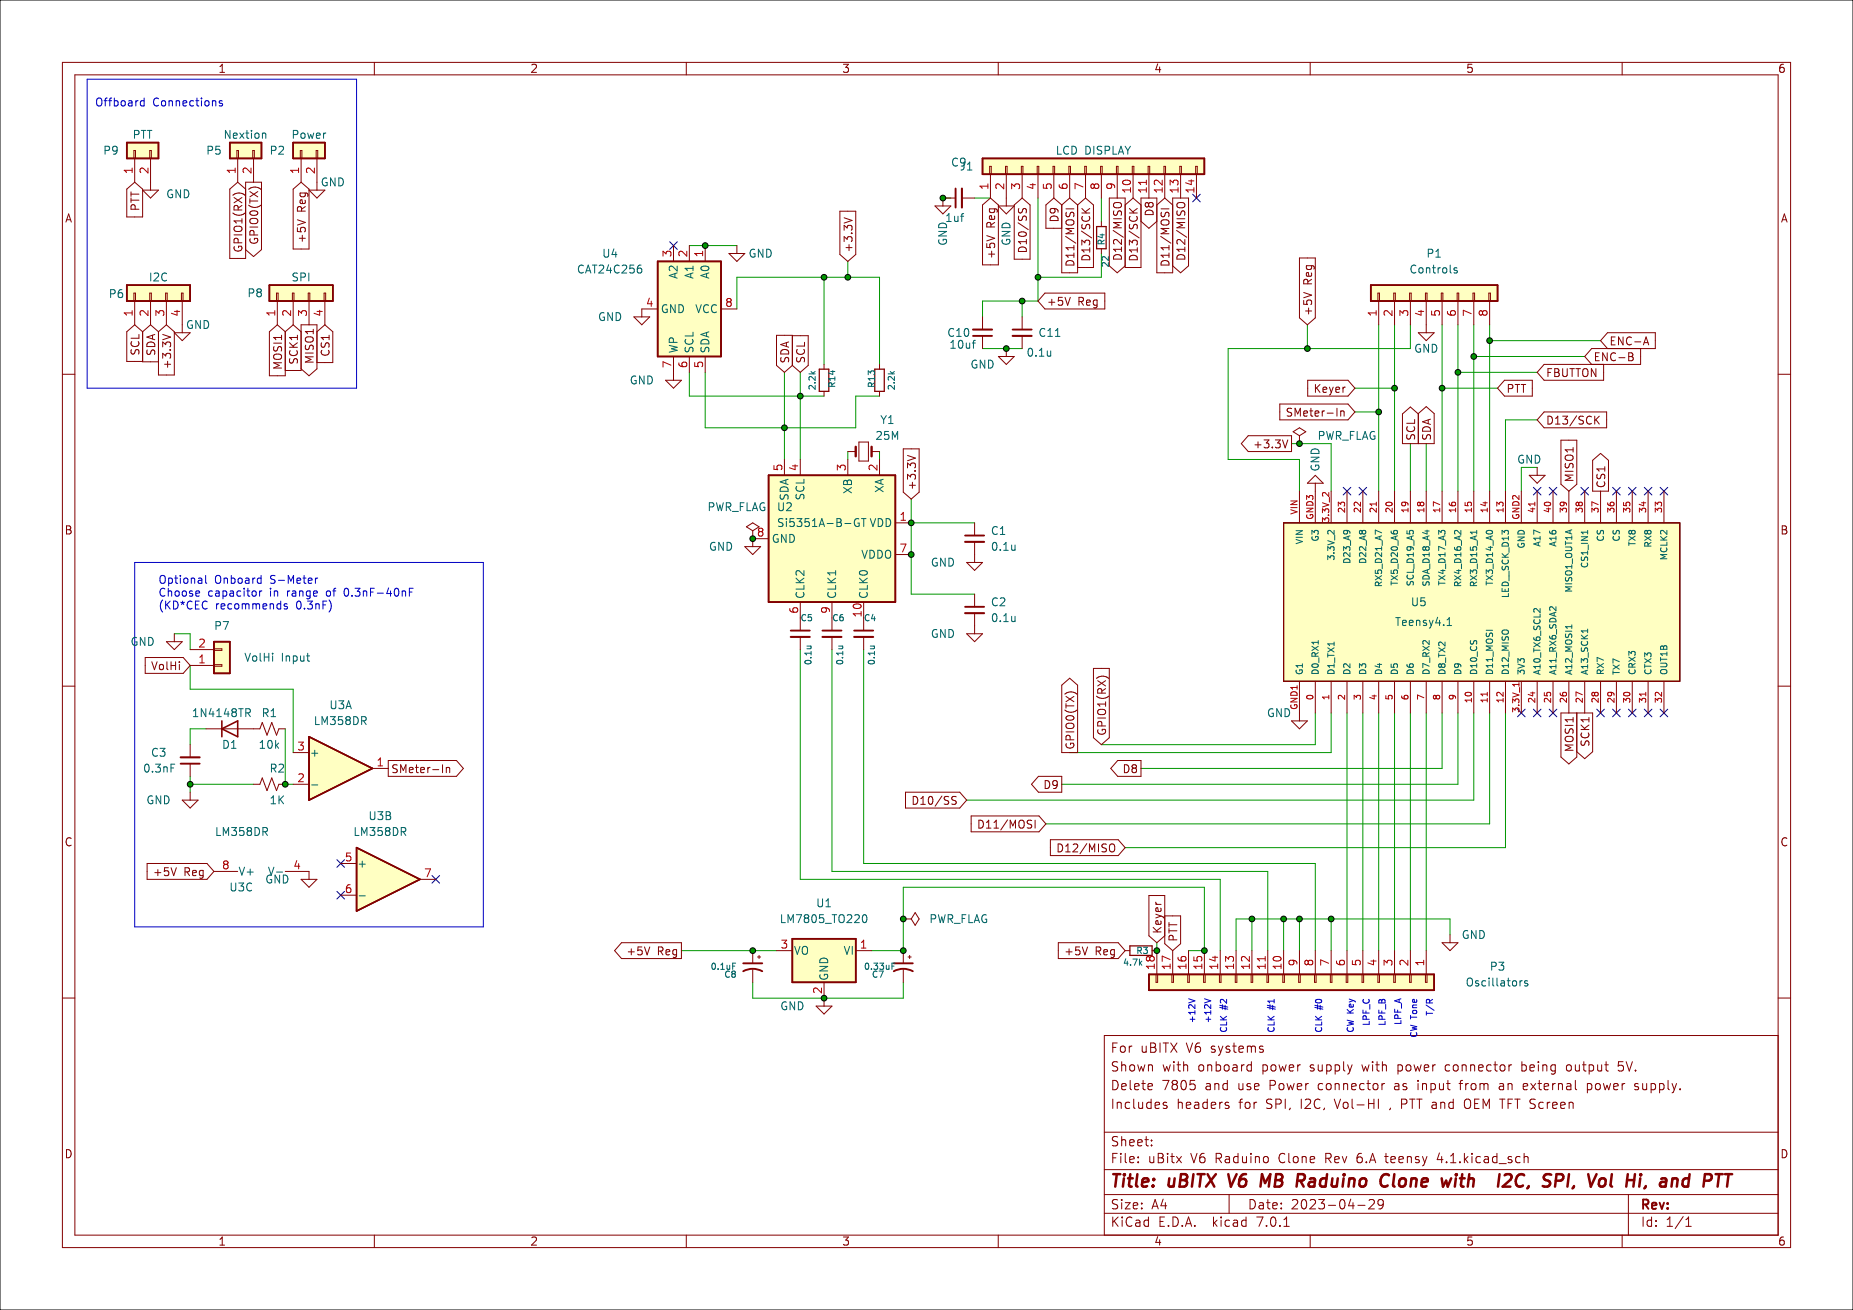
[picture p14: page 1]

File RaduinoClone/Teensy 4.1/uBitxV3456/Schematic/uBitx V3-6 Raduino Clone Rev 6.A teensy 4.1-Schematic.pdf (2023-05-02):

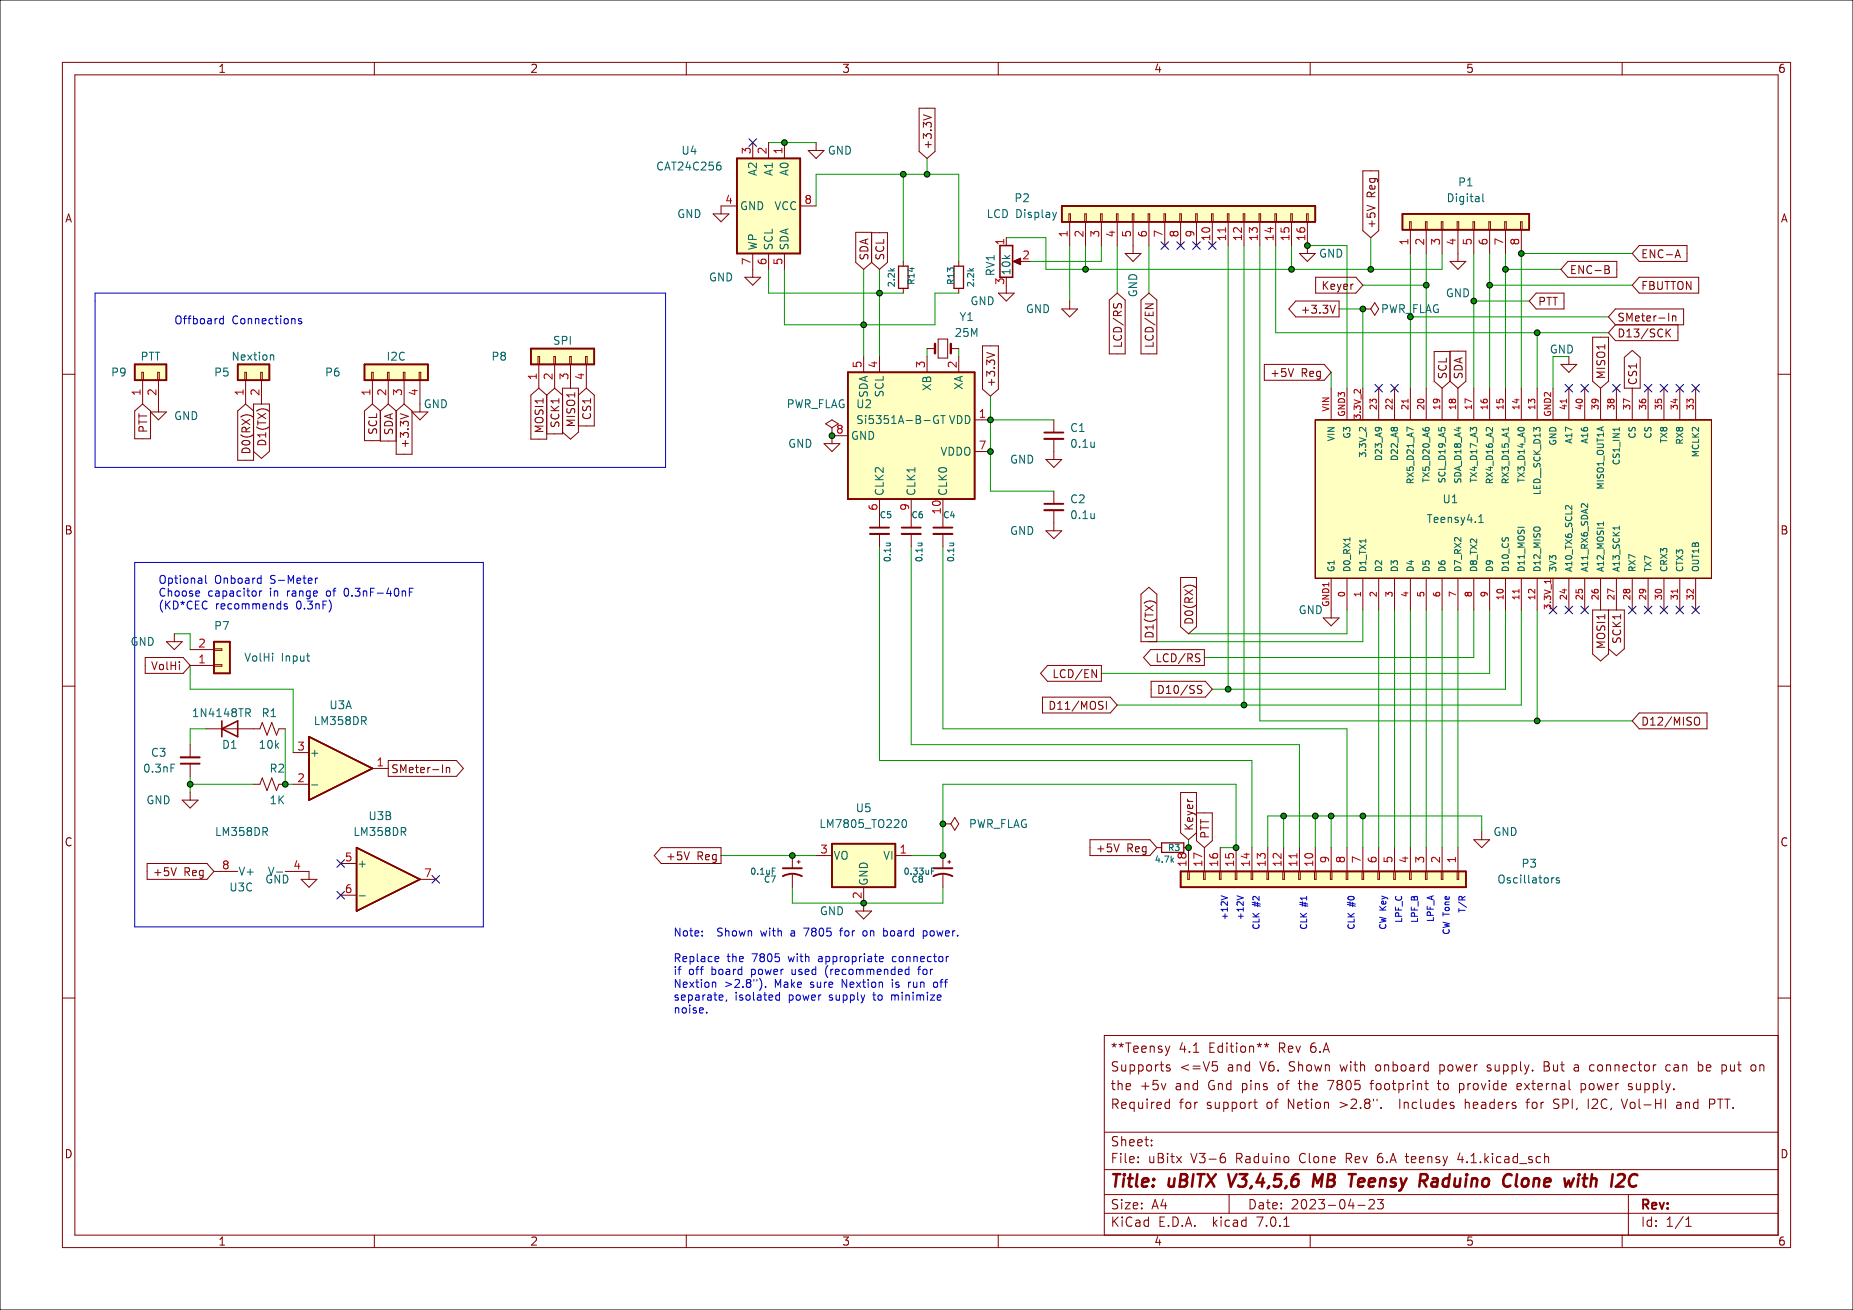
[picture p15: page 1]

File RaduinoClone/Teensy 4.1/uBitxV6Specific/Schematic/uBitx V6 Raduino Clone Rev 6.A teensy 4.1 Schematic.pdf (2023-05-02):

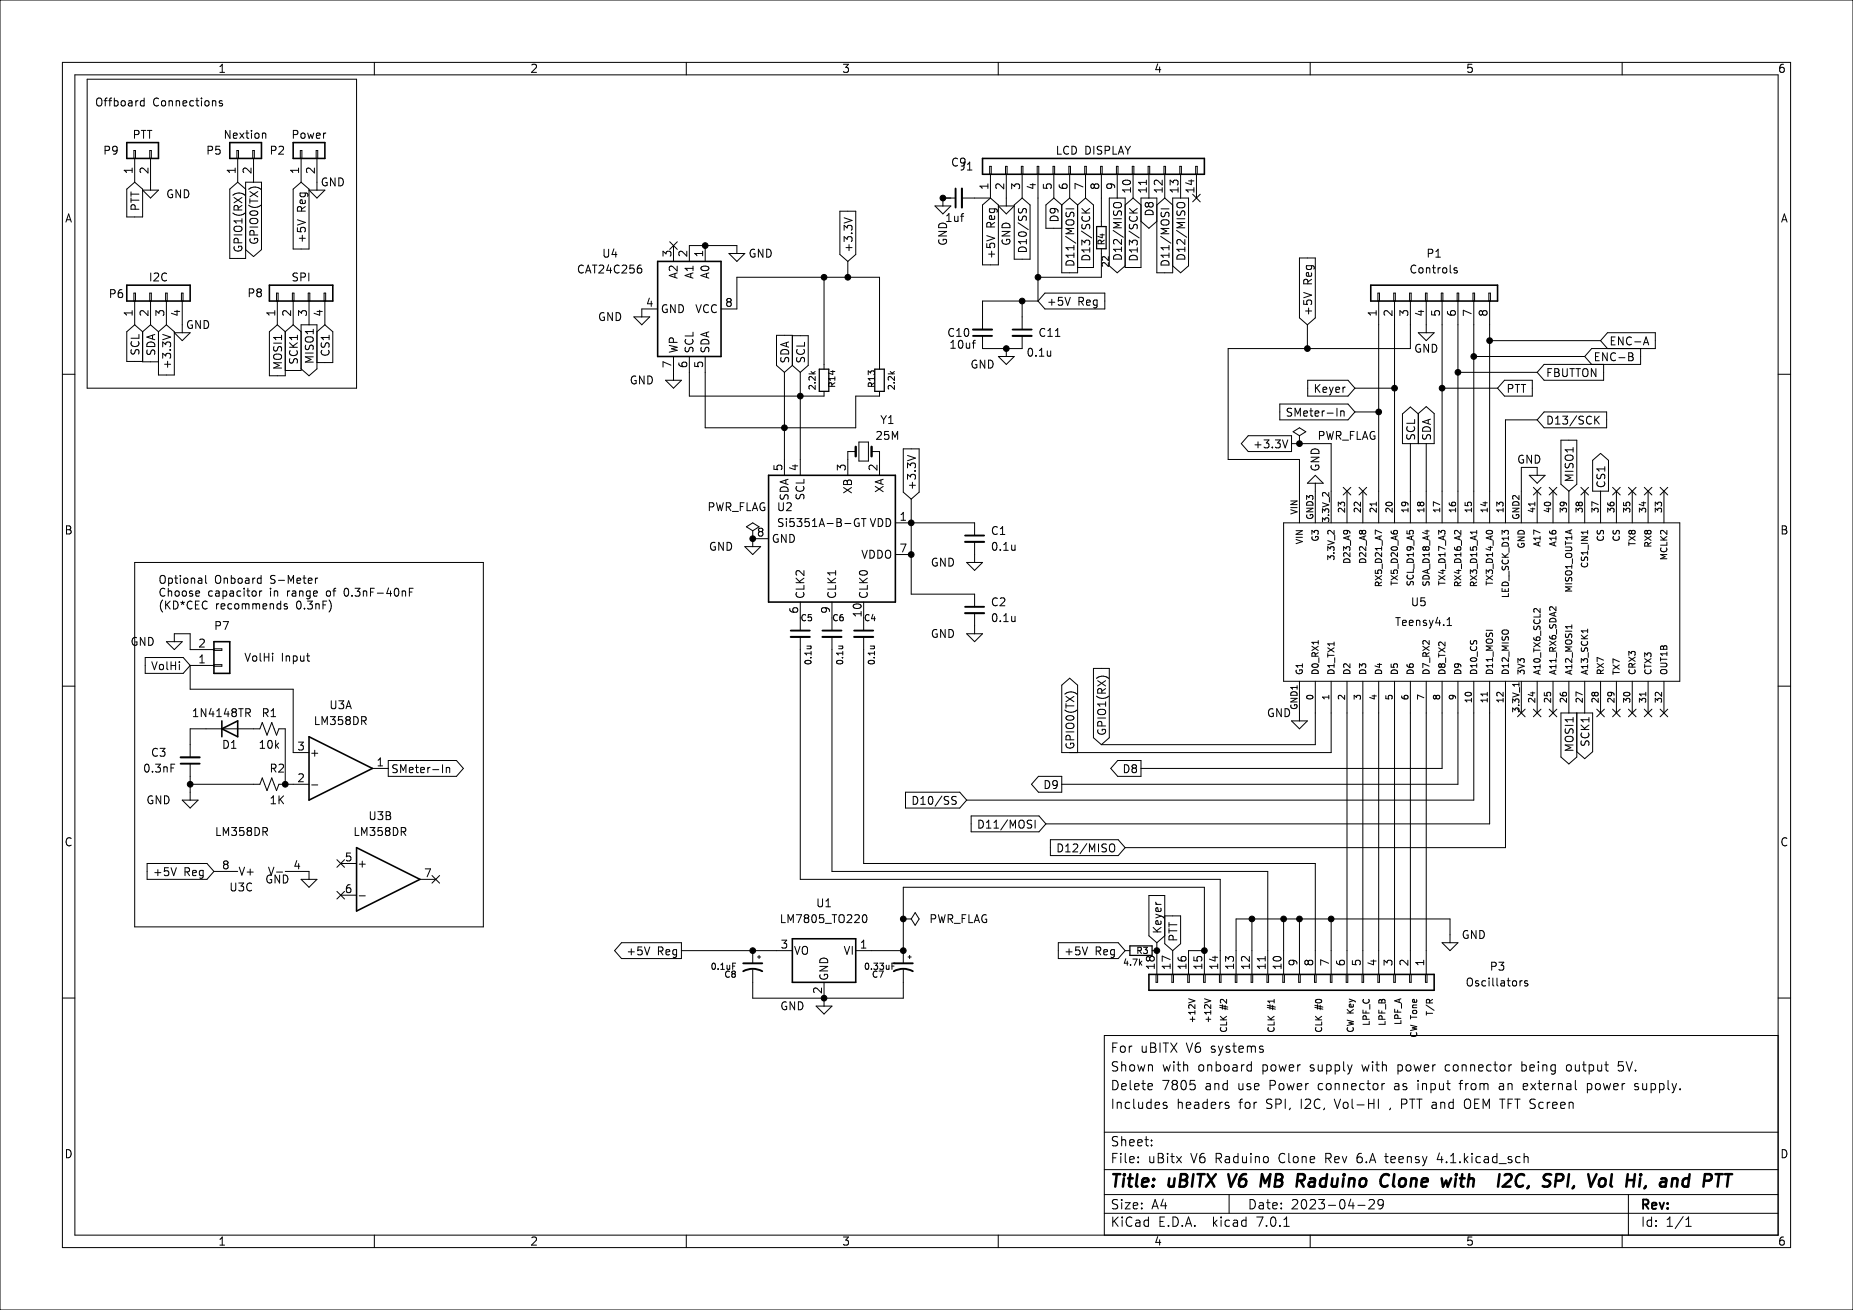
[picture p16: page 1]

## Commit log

2022-07-11 Added kicad archive of Zip
2022-08-10 V2 of main Raduino Clone
    [uBitx Raduino Clone V2-B_Cu.gbr, uBitx Raduino Clone V2-B_Mask.gbr, uBitx Raduino Clone V2-B_Paste.gbr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]
2022-10-13 Renaming folders, preparing for v 1.3
    [uBitx Raduino Clone V2-B_Cu.gbr, uBitx Raduino Clone V2-B_Mask.gbr, uBitx Raduino Clone V2-B_Paste.gbr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]
2022-10-27 Fixed switch of SDA and SCL
2022-10-28 fixed error in pico board
2022-11-27 added onboard documentation for the Nextion connector
2023-01-23 added BOM
    [uBitx Raduino Clone V3 BOM.csv, uBitx Raduino Clone V3 BOM.xlsx, uBitx Raduino Clone V3 with I2C BOM.csv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]
2023-05-02 initial upload of Rev6A designs
    [uBitx Raduino Clone V3 BOM.csv, uBitx Raduino Clone V3 BOM.xlsx, uBitx Raduino Clone V3 with I2C BOM.csv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]
2026-01-31 loaded v10 pico and rpi zero2w
    [uBitx V6 Raduino Clone Rev 10-Optic piZero2w_BOM.csv, uBitx V6 Raduino Clone Rev 10-Optic piZero2w_BOM.xlsx, uBitx V6 Raduino Clone Rev 10-Optic pico_BOM.csv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]
2026-01-31 Update README.md to include V10 RPI Pico and Zero
2026-01-31 Update Readme.md added board photos
